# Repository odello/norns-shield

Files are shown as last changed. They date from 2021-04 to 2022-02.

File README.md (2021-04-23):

# norns-shield



minimal/tiny open-source/DIY shield for Raspberry Pi boards, providing hardware compatibility with the [norns](https://monome.org) ecosystem.

- audio codec: CS4270
- audio jacks: 3.5mm stereo in/out, line level
- OLED: NHD-2.7-12864WDW3
- 3x pushbuttons, 3x rotary encoders

see the full [BOM on Octopart](https://octopart.com/bom-tool/Q3rQej3x)

see [https://llllllll.co/t/diy-norns-shield](https://llllllll.co/t/diy-norns-shield/27638) for discussion.

[monome.org](https://monome.org)

full kit available from [monome.org](https://market.monome.org)





## assembly

for SMD-populated circuit.

parts shown (header already soldered to OLED)



first solder the OLED header (make sure the orientation looks like the photo below, as we've had a few reports of folks placing their headers on the wrong side). then the encoders, and keys.





then attach the pi header to the other side and solder as shown.



attach the screen to the top. note that you may have to apply substantial pressure for it to connect: put something hard on top of the header while applying pressure so you don't wreck your thumbs.

likewise, attaching the keycaps requires substantial pressure. be sure they are aligned well then press hard.

the knobs should go on easily in comparison.

---



attach the shortest spacers with short screws, which props up the screen.



four spacers with the male thread insert from the top. for the bottom, the long remaining spacers go in front, shorter in back as shown.



align the plate and attach with short screws. don't tighten the screws until you've aligned the keys and knobs, as there's a little wiggle room for fine tuning.



attach the pi and add two plastic spacers, then balance the plate on top. the holes with spacers need the two long screws, the front use short screws.



## setting up

get [this shield image from github](https://github.com/monome/norns-image/releases/download/200106/norns200106-shield.img.zip). *nb. image is only compatible with Raspberry Pi 3b+ and Pi 3b. Pi 4 is not supported out of the box. for more detail, see [this thread](https://llllllll.co/t/can-i-use-the-official-norns-shield-w-raspberry-pi-4/31072/3).*

use [etcher](https://www.balena.io/etcher/) to make your SD card. it's by far the most reliable method.

## troubleshooting

- most soldering problems can be solved simply by reheating solder joints. bad solders can result in various problems: screen doesn't turn on, knobs/keys don't work.
- use a good SD card, not a cheap one. if you're having trouble, try using a different card.
- be sure to use the correct power supply. the pi will not power well from a laptop and you'll get confusing errors. get a dedicated 2A USB supply, or very high output USB battery.

if your SD card seems a lot more full than it should be, you'll need to expand the filesystem:
- open a terminal on a computer connected to the same network as your shield
- execute: `ssh we@norns.local`
- password: `sleep`
- execute: `sudo raspi-config`
- navigate to `Advanced` and hit RETURN
- select `expand filesystem` and hit RETURN
- lots of activity will happen. when it's done, power down and reboot. if you get any errors, reboot again.
- if you SSH back into norns and execute `df -h`, you'll see the newly expanded capacity.

## notes

- the shield does not have a headphone output, but headphones work fine on the main output. the headphone gain level within the norns menu does nothing in this case.
- the battery indication will not function, as there's no battery.

## mechanicals

- 2 Female Threaded Hex Standoff Aluminum, 3/16" Hex, 5/16" Long, 2-56 Thread 91780A104
- 2 Female Threaded Hex Standoff Aluminum, 3/16" Hex, 5/8" Long, 2-56 Thread 91780A111
- 2 Female Threaded Hex Standoff Aluminum, 3/16" Hex, 3/4" Long, 2-56 Thread 91780A113
- 4 Male-Female Threaded Hex Standoff Aluminum, 3/16" Hex Size, 1/2" Long, 2-56 Thread Size 93505A213
- 4 Off-White Nylon Unthreaded Spacer 1/4" OD, 3/32" Long, for Number 6 Screw Size 94639A247
- 8 Black-Oxide 18-8 Stainless Steel Pan Head Phillips Screws 2-56 Thread, 1/4" Long 91249A050
- 2 Black-Oxide 18-8 Stainless Steel Pan Head Phillips Screws 2-56 Thread, 3/8" Long 91249A054

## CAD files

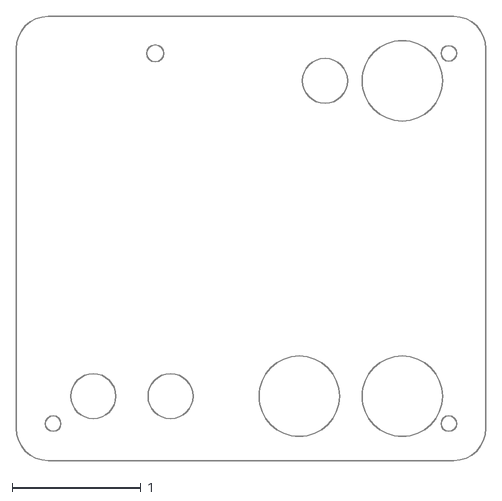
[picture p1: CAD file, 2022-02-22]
eagle/norns-shield-plate.dxf
3.65 x 3.45

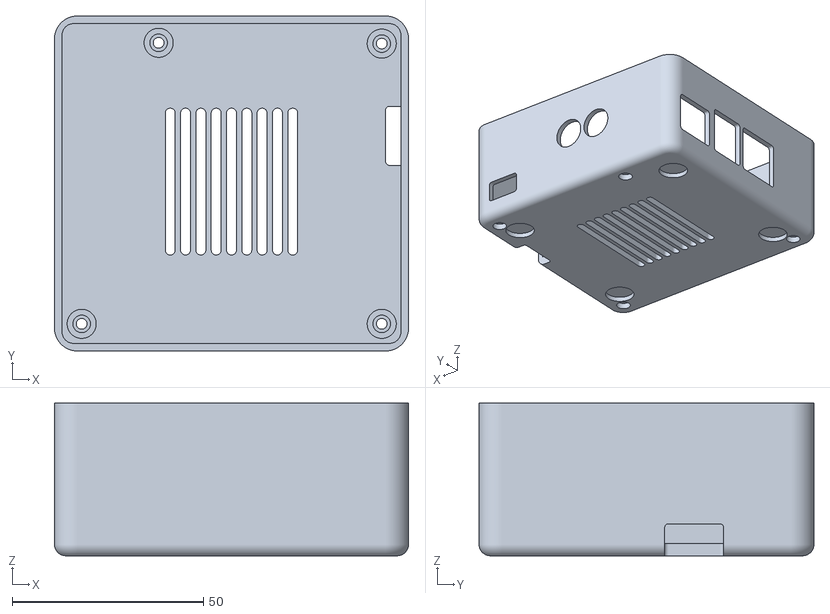
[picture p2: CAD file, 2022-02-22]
norns-shield.stl
92.5 x 87.5 x 39.8

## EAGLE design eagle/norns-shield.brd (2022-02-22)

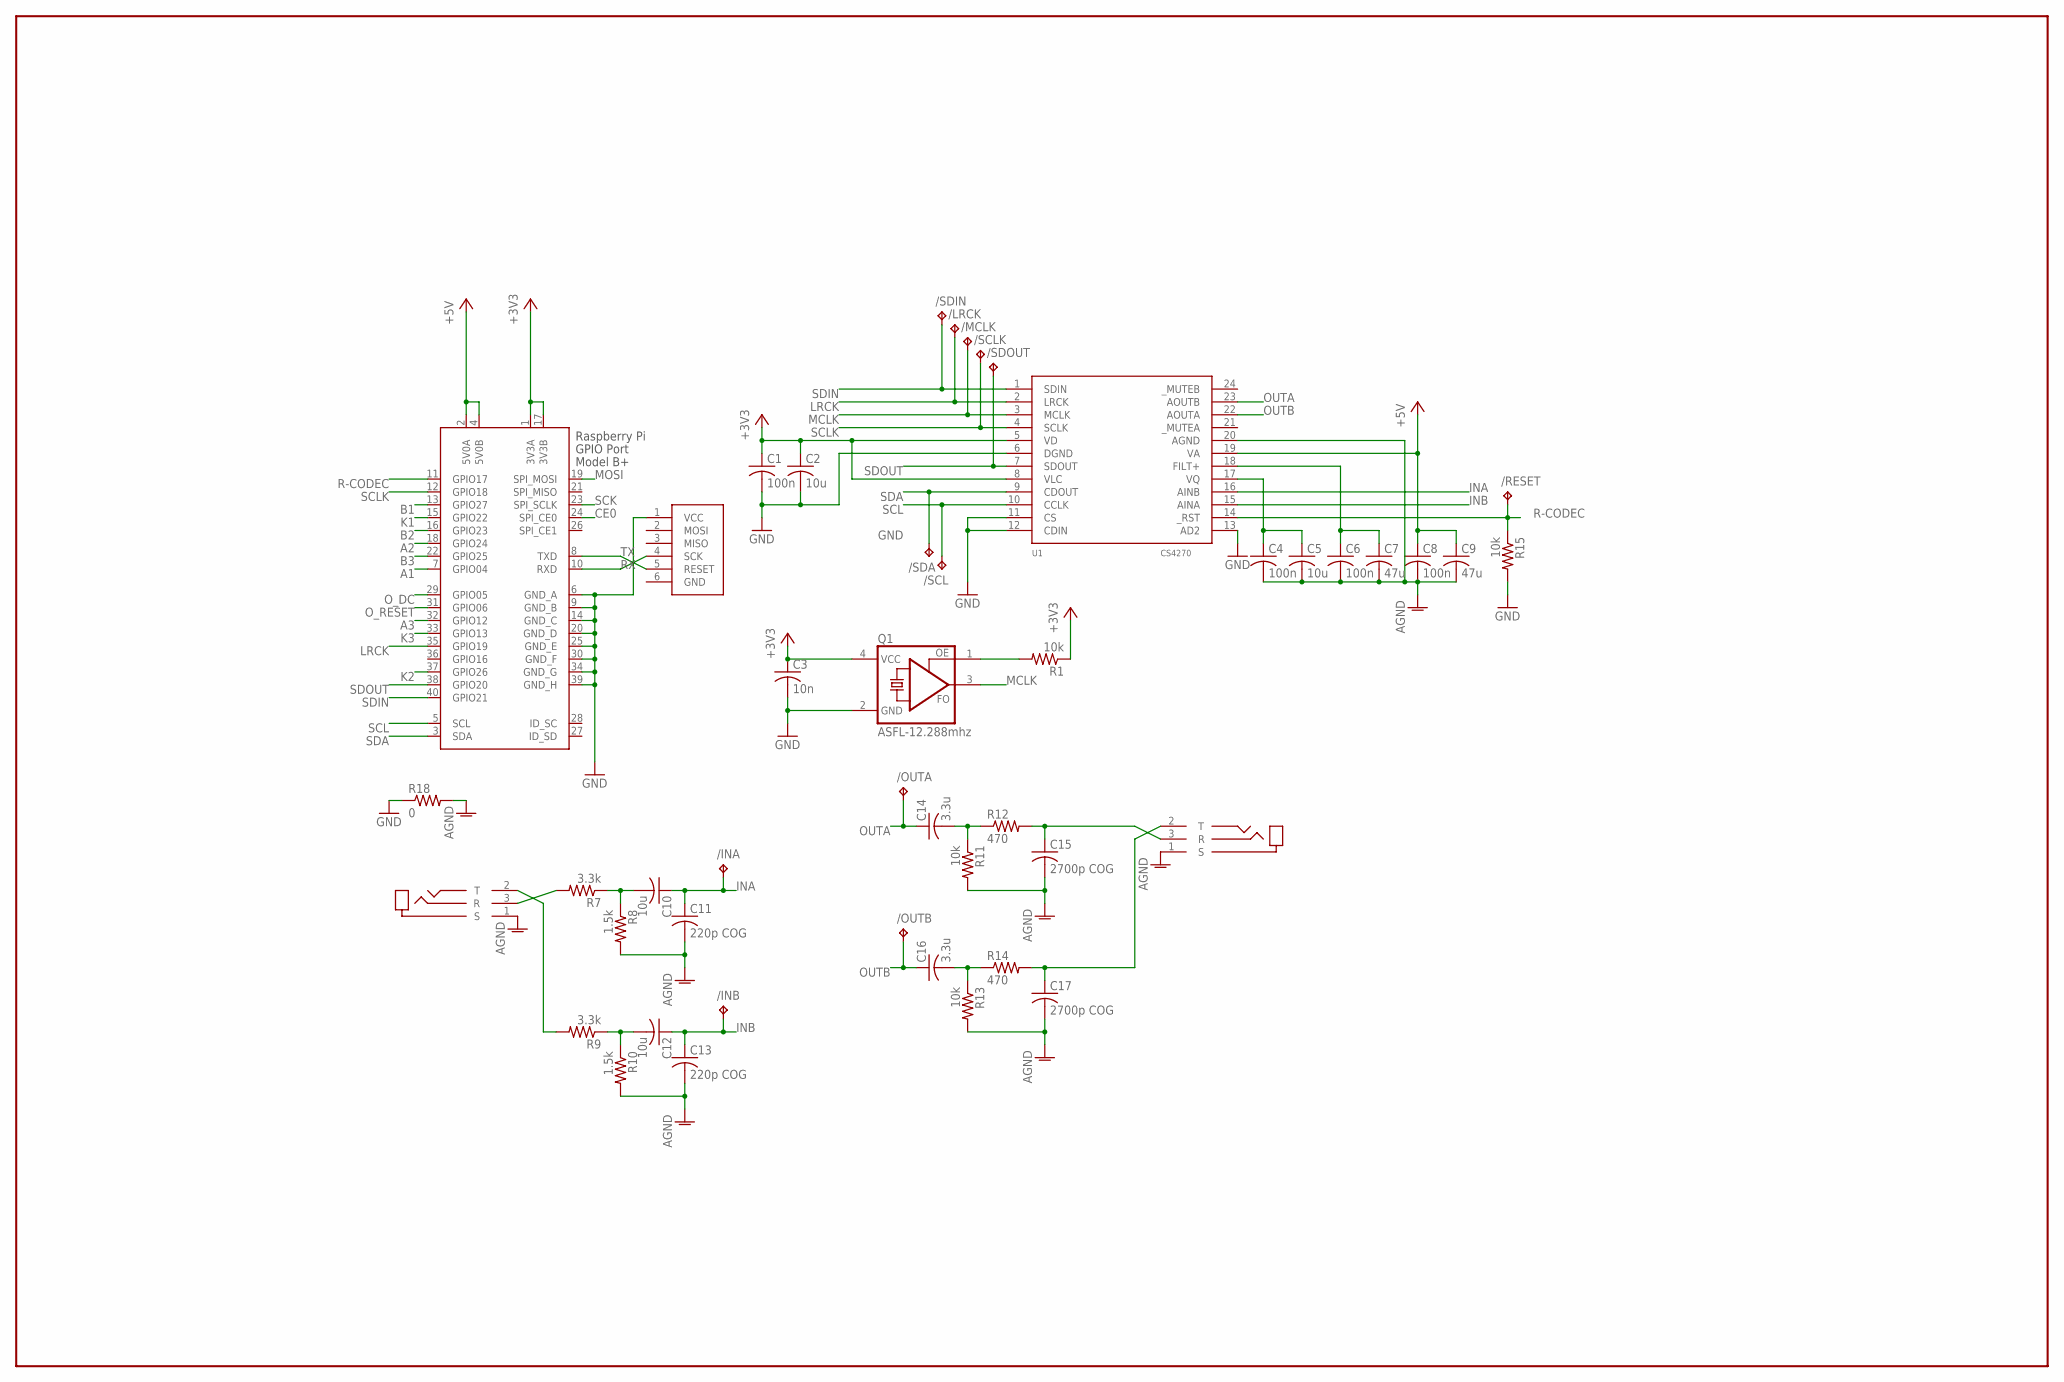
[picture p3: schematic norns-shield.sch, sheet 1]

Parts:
/INA: TPTP12R; TP12R
/INB: TPTP12R; TP12R
/LRCK: TPTP12R; TP12R
/MCLK: TPTP12R; TP12R
/OUTA: TPTP12R; TP12R
/OUTB: TPTP12R; TP12R
/RESET: TPTP12R; TP12R
/SCL: TPTP12R; TP12R
/SCLK: TPTP12R; TP12R
/SDA: TPTP12R; TP12R
/SDIN: TPTP12R; TP12R
/SDOUT: TPTP12R; TP12R
C1, C4, C6, C8: 100n; C0603
C2, C5, C10, C12: 10u; C0805
C3: 10n; C0603
C7, C9: 47u; C1206
C11, C13: 220p COG; C0603
C14, C16: 3.3u; C0805
C15, C17: 2700p COG; C0603
J1: TRS-IN; SJ-3523-SMT
J2: TRS-OUT; SJ-3523-SMT
J3: ISP-ROW
Q1: ASFL-12.288mhz; ASF
R1, R11, R13, R15: 10k; R0603
R7, R9: 3.3k; R0603
R8, R10: 1.5k; R0603
R12, R14: 470; R0603
R18: 0; R0603
U1: CS4270; TSSOP24
X1: RASPI_BOARD_B+#_E3; RASPI_BOARD_B+_EDGES_3DRILL

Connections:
+3V3: C1.1, C2.1, C3.1, Q1.4 (VCC), R1.1, U1.5 (VD), U1.8 (VLC), X1.1 (3V3A), X1.17 (3V3B); also elsewhere on the board
+5V: C8.1, C9.1, U1.19 (VA), X1.2 (5V0A), X1.4 (5V0B)
A1: X1.7 (GPIO04); also elsewhere on the board
A2: X1.18 (GPIO24); also elsewhere on the board
A3: X1.32 (GPIO12); also elsewhere on the board
AGND: C4.2, C5.2, C6.2, C7.2, C8.2, C9.2, C11.2, C13.2, C15.2, C17.2, J1.1 (S), J2.1 (S), R8.2, R10.2, R11.2, R13.2, R18.2, U1.20 (AGND)
B1: X1.13 (GPIO27); also elsewhere on the board
B2: X1.16 (GPIO23); also elsewhere on the board
B3: X1.22 (GPIO25); also elsewhere on the board
CE0: X1.24 (SPI_CE0); also elsewhere on the board
GND: C1.2, C2.2, C3.2, J3.1 (VCC), Q1.2 (GND), R15.2, R18.1, U1.6 (DGND), U1.11 (CS), U1.12 (CDIN), U1.13 (AD2), X1.6 (GND_A), X1.9 (GND_B), X1.14 (GND_C), X1.20 (GND_D), X1.25 (GND_E), X1.30 (GND_F), X1.34 (GND_G), X1.39 (GND_H); also elsewhere on the board
INA: /INA.TP, C10.1, C11.1, U1.16 (AINB)
INB: /INB.TP, C12.1, C13.1, U1.15 (AINA)
K1: X1.15 (GPIO22); also elsewhere on the board
K2: X1.37 (GPIO26); also elsewhere on the board
K3: X1.33 (GPIO13); also elsewhere on the board
LRCK: /LRCK.TP, U1.2 (LRCK), X1.35 (GPIO19)
MCLK: /MCLK.TP, Q1.3 (FO), U1.3 (MCLK)
MOSI: X1.19 (SPI_MOSI); also elsewhere on the board
unnamed: Q1.1 (OE), R1.2
unnamed: C4.1, C5.1, U1.17 (VQ)
unnamed: C6.1, C7.1, U1.18 (FILT+)
unnamed: J1.3 (R), R7.2
unnamed: C10.2, R7.1, R8.1
unnamed: C12.2, R9.1, R10.1
unnamed: J1.2 (T), R9.2
unnamed: C16.2, R13.1, R14.1
unnamed: C14.2, R11.1, R12.1
unnamed: C15.1, J2.3 (R), R12.2
unnamed: C17.1, J2.2 (T), R14.2
OUTA: /OUTA.TP, C14.1, U1.23 (AOUTB)
OUTB: /OUTB.TP, C16.1, U1.22 (AOUTA)
O_DC: X1.29 (GPIO05); also elsewhere on the board
O_RESET: X1.31 (GPIO06); also elsewhere on the board
R-CODEC: /RESET.TP, R15.1, U1.14 (_RST), X1.11 (GPIO17)
RX: J3.4 (SCK), X1.10 (RXD)
SCK: X1.23 (SPI_SCLK); also elsewhere on the board
SCL: /SCL.TP, U1.10 (CCLK), X1.5 (SCL)
SCLK: /SCLK.TP, U1.4 (SCLK), X1.12 (GPIO18)
SDA: /SDA.TP, U1.9 (CDOUT), X1.3 (SDA)
SDIN: /SDIN.TP, U1.1 (SDIN), X1.40 (GPIO21)
SDOUT: /SDOUT.TP, U1.7 (SDOUT), X1.38 (GPIO20)
TX: J3.5 (RESET), X1.8 (TXD)

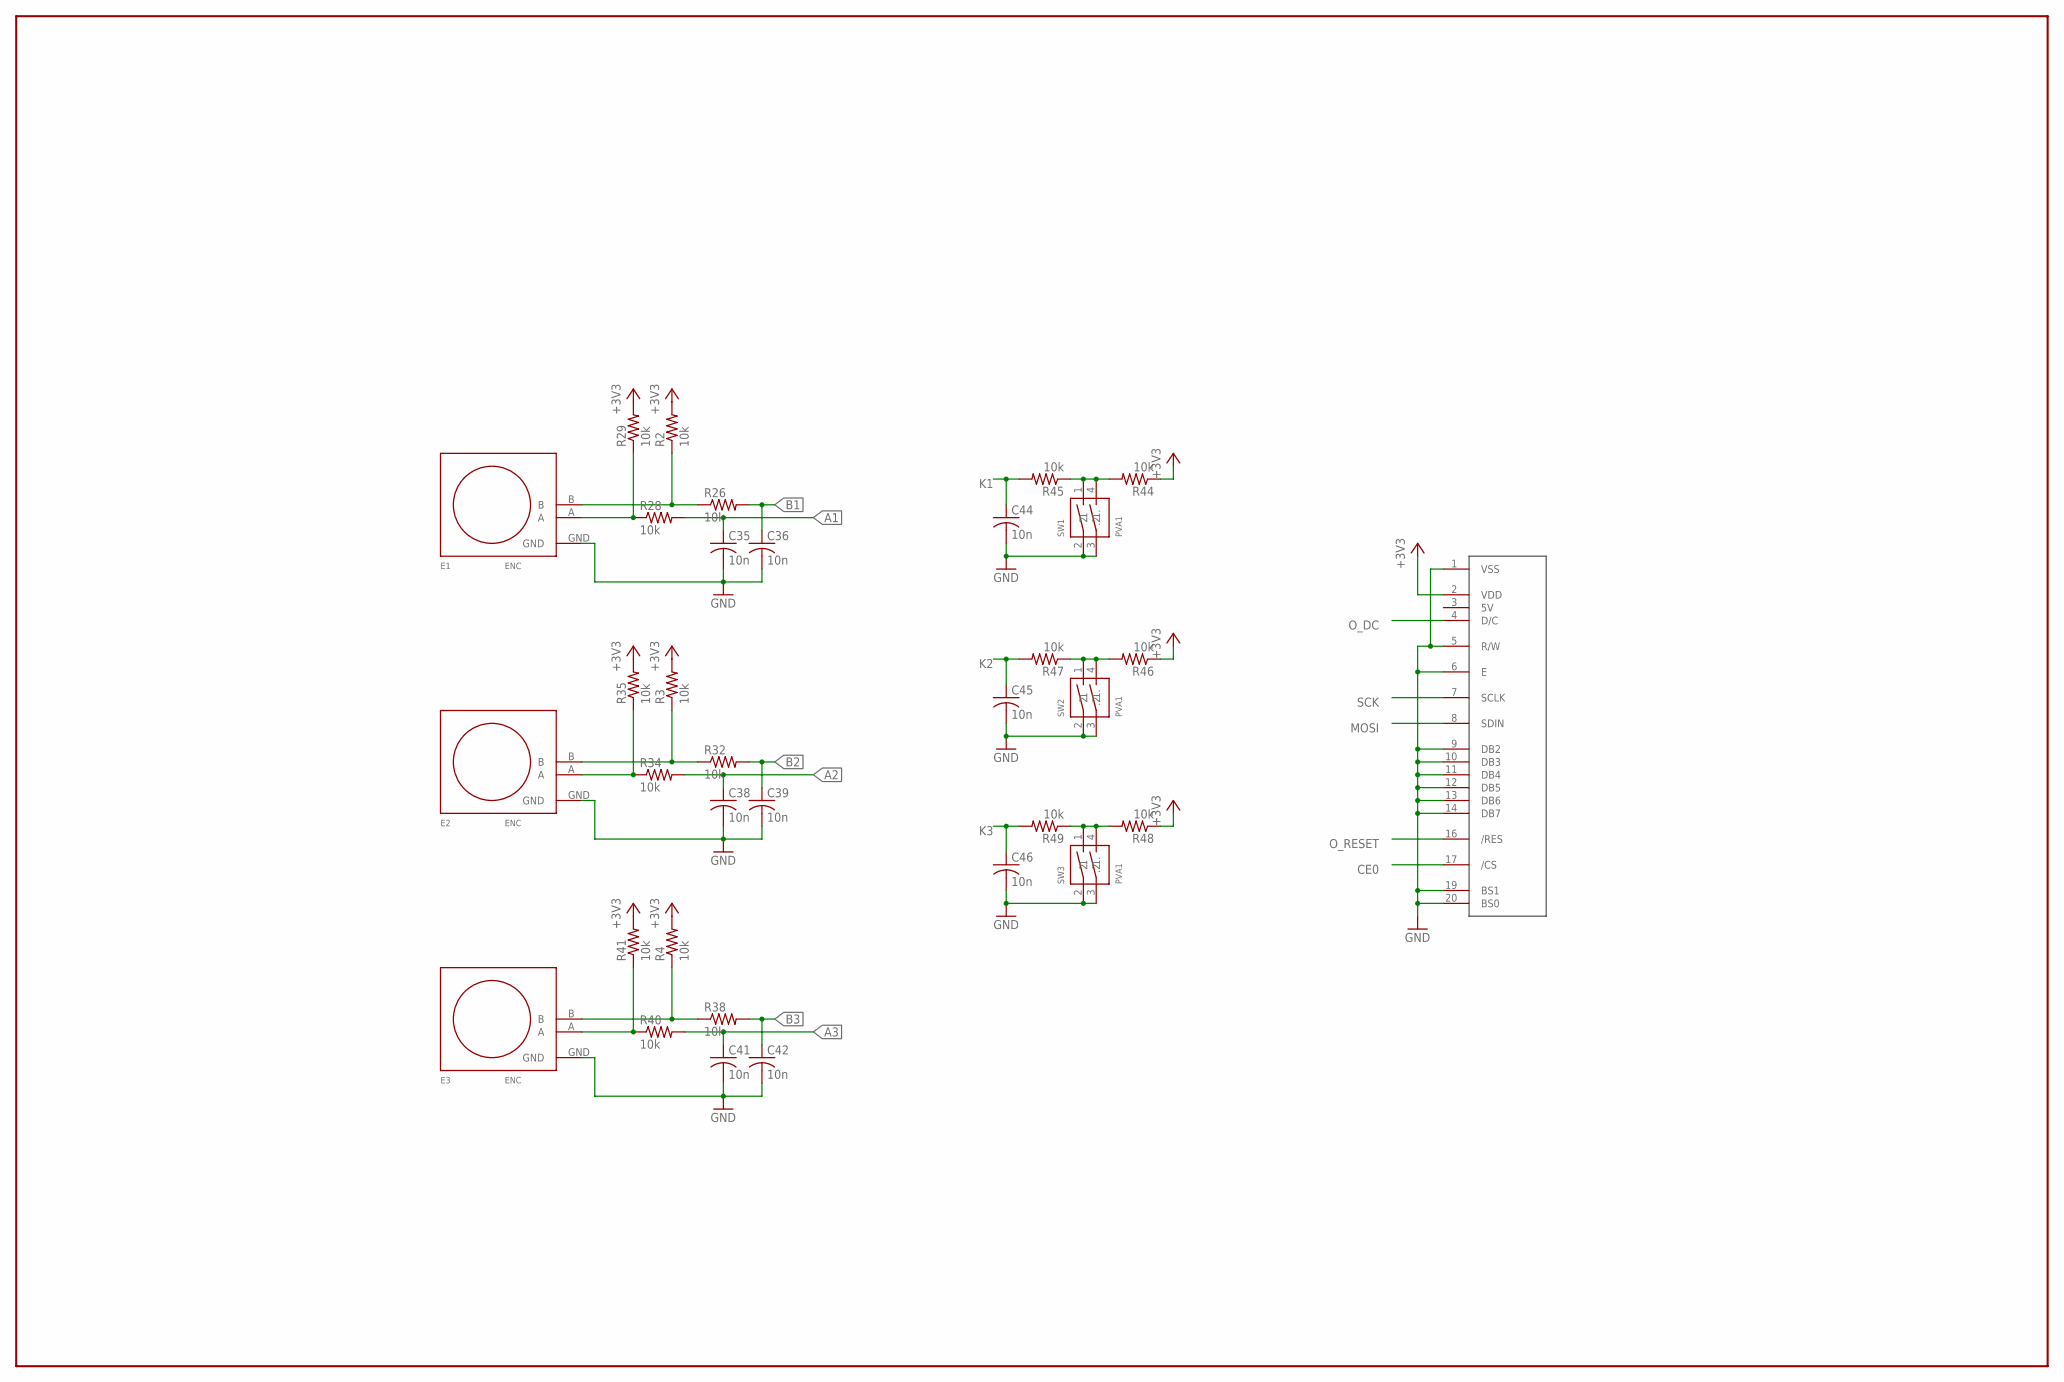
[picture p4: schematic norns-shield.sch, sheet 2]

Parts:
C35, C36, C38, C39, C41, C42, C44, C45, C46: 10n; C0603
E1, E2, E3: ENC; PEC11RN
R2, R3, R4, R26, R28, R29, R32, R34, R35, R38, R40, R41, R44, R45, R46, R47, R48, R49: 10k; R0603
SW1, SW2, SW3: PVA1
U$1: OLED128X64; OLED-ALEPH

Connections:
+3V3: R2.2, R3.2, R4.2, R29.2, R35.2, R41.2, R44.1, R46.1, R48.1, U$1.2 (VDD); also elsewhere on the board
A1: C35.1, R28.2; also elsewhere on the board
A2: C38.1, R34.2; also elsewhere on the board
A3: C41.1, R40.2; also elsewhere on the board
B1: C36.1, R26.2; also elsewhere on the board
B2: C39.1, R32.2; also elsewhere on the board
B3: C42.1, R38.2; also elsewhere on the board
CE0: U$1.17 (/CS); also elsewhere on the board
GND: C35.2, C36.2, C38.2, C39.2, C41.2, C42.2, C44.2, C45.2, C46.2, E1.GND, E2.GND, E3.GND, SW1.2 (1), SW1.3 (1.), SW2.2 (1), SW2.3 (1.), SW3.2 (1), SW3.3 (1.), U$1.1 (VSS), U$1.5 (R/W), U$1.6 (E), U$1.9 (DB2), U$1.10 (DB3), U$1.11 (DB4), U$1.12 (DB5), U$1.13 (DB6), U$1.14 (DB7), U$1.19 (BS1), U$1.20 (BS0); also elsewhere on the board
K1: C44.1, R45.2; also elsewhere on the board
K2: C45.1, R47.2; also elsewhere on the board
K3: C46.1, R49.2; also elsewhere on the board
MOSI: U$1.8 (SDIN); also elsewhere on the board
unnamed: R44.2, R45.1, SW1.1 (2), SW1.4 (.2)
unnamed: R46.2, R47.1, SW2.1 (2), SW2.4 (.2)
unnamed: R48.2, R49.1, SW3.1 (2), SW3.4 (.2)
unnamed: E1.A, R28.1, R29.1
unnamed: E1.B, R2.1, R26.1
unnamed: E2.B, R3.1, R32.1
unnamed: E2.A, R34.1, R35.1
unnamed: E3.B, R4.1, R38.1
unnamed: E3.A, R40.1, R41.1
O_DC: U$1.4 (D/C); also elsewhere on the board
O_RESET: U$1.16 (/RES); also elsewhere on the board
SCK: U$1.7 (SCLK); also elsewhere on the board

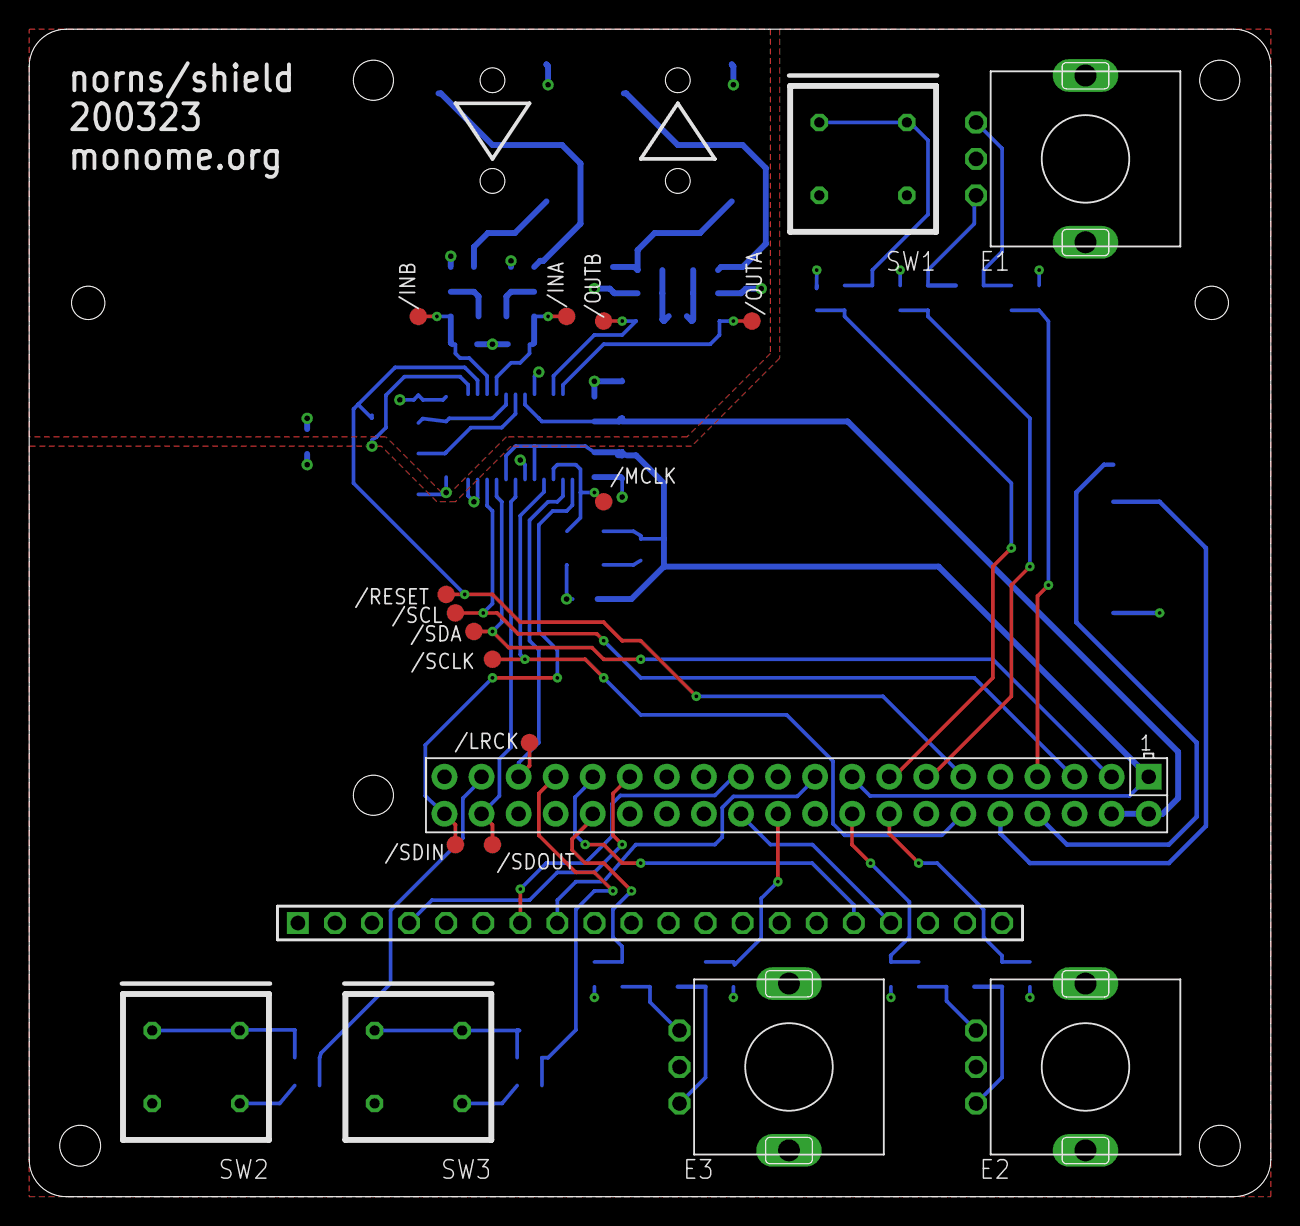
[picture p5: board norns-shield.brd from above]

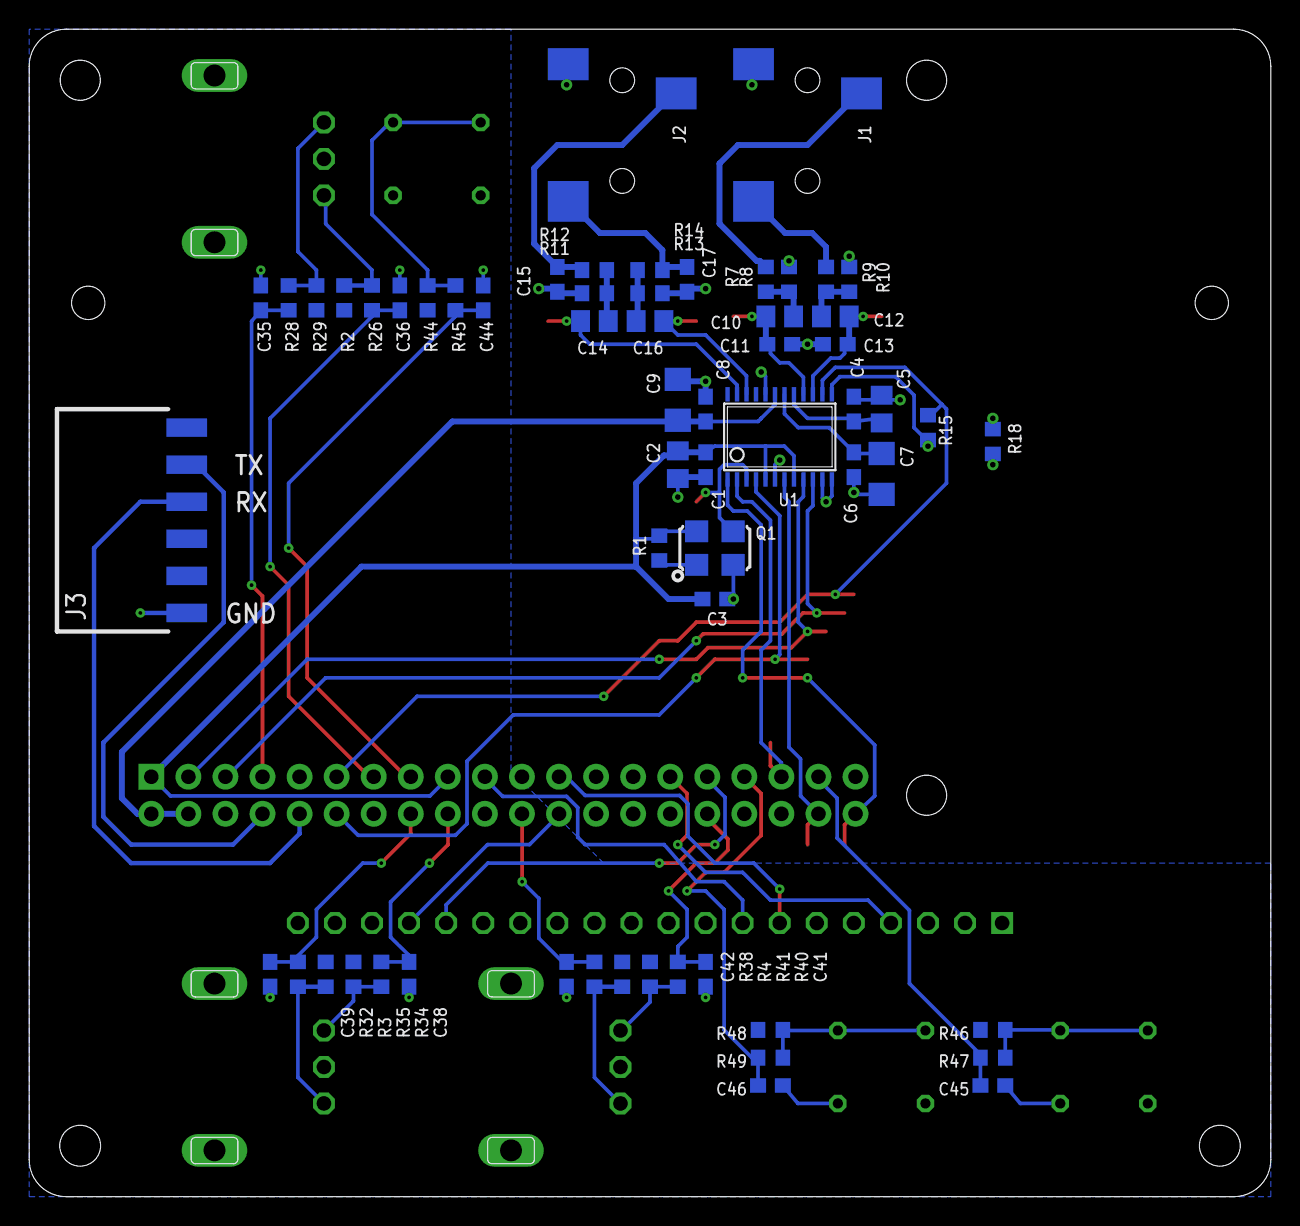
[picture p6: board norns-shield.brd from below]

Board: 2 copper layers, 85.1 x 80.0 mm, 80 parts (60 on the bottom side), 52 nets.
